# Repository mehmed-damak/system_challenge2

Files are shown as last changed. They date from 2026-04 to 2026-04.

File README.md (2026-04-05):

# SafeShift
SafeShift is a system meant to be retrofitted on new and/or old industrial vehicles. The Goal of Safeshift is to provide assistance in preventative maintenance and in safety (and limited power tracking to where it applies). SafeShift is meant to be modular and be a plug and play module, that can work on any vehicle both new and old.

## Physical Installation
The main SafeShift board is to be placed in space inside the drivers cabin. and the sensors respective connectors will be plugged into them. The sensors are to be bolted/fasted to their repective areas (defined below). _NOTE: not ALL sensors must be connected to use SafeShift_




## Connectivity and Dashboard
The Preventative Maintenance Part of the systam connects to a dashboard through wifi or bluetooth, and provides sensor reading, both past and present. A simple learning model from previous data shows the current status of the system based on the data gathered. 

## Safety 
SafeShift uses a combination of sensors to ensure real-time safety monitoring and intelligent decision-making in industrial vehicles. It integrates JSN-SR04T (ultrasonic sensor) for proximity and obstacle detection, RCWL-0516 (microwave radar sensor) for motion detection, ADXL345 (MEMS accelerometer) for vibration and tilt monitoring, DS18B20 (digital temperature sensor) for thermal monitoring, WCS1500 (Hall-effect current sensor) for system current measurement, and A3144 (Hall-effect sensor) for position and magnetic detection. These sensors enable features such as blind spot detection, pedestrian awareness, and environment-adaptive responses in dynamic industrial settings. Together, this multi-sensor approach provides reliable, low-cost, and scalable safety coverage, significantly improving operational safety and system awareness.

## Preventative Maintenance
SafeShift tracks the following parameters in Industrial Vehicles: Vibration in motor pumps, temperature of motor-pumps. it uses a simple DS18B20 to track temperature sensors and an ADXL345 for vibrations. There are 4 of each applicable to this system.

## Energy Tracking 
If the vehicle is equipped with an electrical system, consumption is monitored via real-time current data shown on the dashboard through the current sensor.
Note: The voltage is to be set by the user following the vehicles specifications.

## Usage
SafeShift is designed for simple and intuitive usage, requiring the operator to download and launch the mobile application and connect to the system via WiFi or Bluetooth.

run app

Once connected, the dashboard provides real-time monitoring of vehicle status and safety conditions.

If proximity is detected, a buzzer alarm is activated. 
If a pedestrian is detected, a buzzer alarm is also triggered. 
If the seatbelt is not fastened, an LED indicator is activated. 
If the door is not properly closed, an LED indicator is turned on. 
If the load is too heavy, a pressure LED is activated.

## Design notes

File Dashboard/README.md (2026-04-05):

# SafeShift — Vehicle Safety & Maintenance Dashboard

A student engineering competition project simulating a retrofit IoT safety
system for industrial excavators. Real-time sensor simulation with an embedded
XGBoost failure prediction model.

---

## Project structure

```
SafeShift/
├── server.py            # Python WebSocket simulation backend
├── dashboard.html       # Single-file frontend (open directly in browser)
├── retrain.py           # Model retraining script
├── xgboost_model.pkl    # Trained XGBoost failure prediction model
├── ai4i_fe.csv          # Training dataset (AI4I 2020 Predictive Maintenance)
├── requirements.txt     # Python dependencies
└── README.md
```

---

## Quick start

### 1. Create a virtual environment and install dependencies

```bash
python3 -m venv .venv
source .venv/bin/activate        # Windows: .venv\Scripts\activate
pip install -r requirements.txt
```

### 2. Start the server

```bash
python server.py
```

You should see:

```
====================================================
  SafeShift server running on ws://localhost:8765
  Open dashboard.html in your browser
  Press Ctrl+C to stop
====================================================
[AI] XGBoost failure model loaded successfully.
```

### 3. Open the dashboard

Open `dashboard.html` directly in your browser (no web server needed).

---

## Architecture

```
dashboard.html  ──WebSocket──▶  server.py
   (browser)    ◀──JSON 500ms──  (Python asyncio)
                                     │
                                     ├─ Sensor simulation classes
                                     ├─ ESP32Controller (safety logic)
                                     └─ FailurePredictor (XGBoost)
```

### Backend (`server.py`)

Simulates a full sensor suite and broadcasts a JSON state object to all
connected clients every 500 ms:

| Sensor class | Simulates |
|---|---|
| `HydraulicPressureSensor` | 0–400 bar with noise + spike suppression |
| `TemperatureSensor`  | Thermal lag model, scales with RPM |
| `VibrationSensor` | RPM-dependent + optional fault injection |
| `RuntimeCounter` | Service hours meter (accelerated for demo) |

The `ESP32Controller` class enforces safety interlocks:
- Relay opens if door is open, seatbelt is off, or pressure exceeds 280 bar
- Alerts are debounced (same alert cannot repeat within 3 seconds)
- Alert log capped at 50 entries, newest first

### Frontend (`dashboard.html`)

- Vanilla JS + CSS, no build step, no npm
- Chart.js (CDN) for the temperature sparkline only
- WebSocket auto-reconnects every 2 seconds if the server drops

---

## AI Failure Prediction

The XGBoost model predicts machine failure probability using only the three
inputs available from the dashboard:

| Dashboard data | Model feature |
|---|---|
| Air temperature (°C) | Air temperature (K) |
| Motor RPM | Rotational speed (rpm) |
| Service hours | Tool wear (min, scaled)  |

Two derived features are computed on the fly:
- `omega` = rpm × 2π / 60
- `pct_tool_life` = tool_wear / 220

**Model performance** (test set, 20% holdout, stratified):

| Metric | Value |
|---|---|
| ROC-AUC | 0.92  |
| PR-AUC | 0.33  |
| Recall (failure class) | 0.52 |

> PR-AUC is the most meaningful metric here given the 97/3 class imbalance.
> The model is weighted with `scale_pos_weight` to improve minority class recall.

### Retraining

To retrain the model from the raw dataset:

```bash
python retrain.py
```

This will clean the data (drops 27 inconsistent label rows), re-engineer
features, retrain with the same hyperparameters, print evaluation metrics,
and overwrite `xgboost_model.pkl`.

---

## Operator controls

| Control | Effect |
|---|---|
| Hydraulic pressure | Sets pressure set-point (0–400 bar) |
| Motor RPM | Sets motor speed (0–2500 rpm) |
| Air temperature | Overrides the thermal simulation (20–130 °C) |
| Service hours | Sets the runtime counter (0–500 h) |
| Door open toggle | Opens the cab door → triggers interlock |
| Seatbelt removed | Removes seatbelt → triggers interlock |
| Inject vibration fault | Adds a 2.5 g spike to the vibration sensor |
| Connect Bluetooth | UI indicator only (no real connection) |
| Internet | UI indicator only (no real connection) |

---

## Dependencies

| Package | Version  | Purpose |
|---|---|---|
| websockets | ≥ 16.0 | Async WebSocket server |
| xgboost | ≥ 3.2.0  | Failure prediction model |
| scikit-learn | ≥ 1.7.0  | Train/test split, metrics |
| numpy | ≥ 2.2.0  | Numerical computation |
| pandas | ≥ 2.3.0  | Feature DataFrame construction |

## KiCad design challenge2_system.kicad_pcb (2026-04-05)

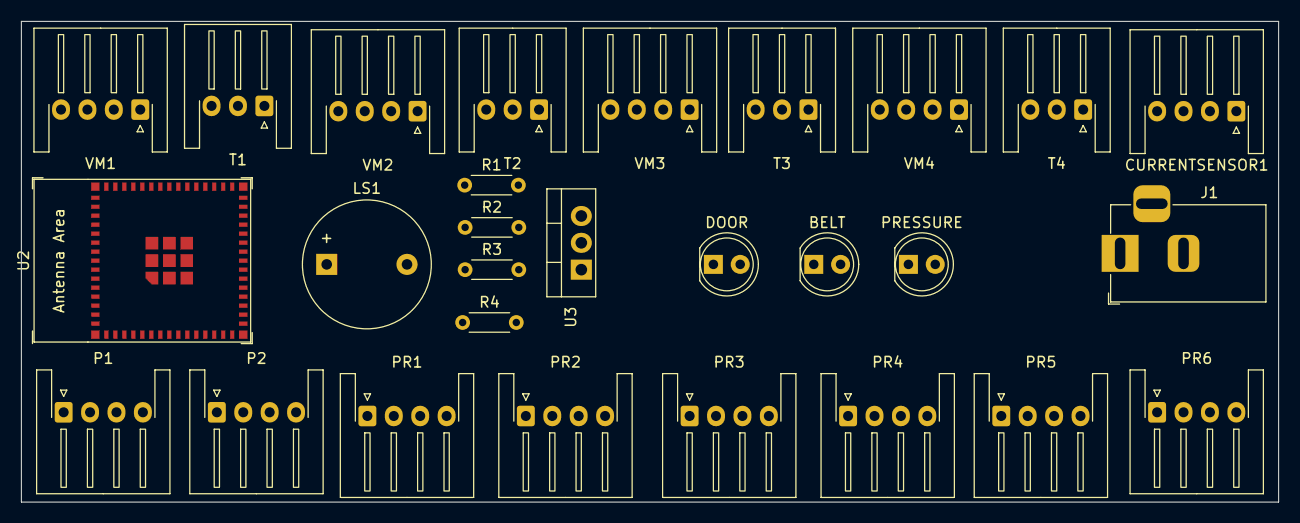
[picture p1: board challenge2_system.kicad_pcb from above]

Board: 2 copper layers, 119.0 x 45.5 mm, 28 parts (0 on the bottom side), 40 nets, no tracks yet.

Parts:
BELT: LED; LED_D5.0mm
CURRENTSENSOR1: Conn_01x04_Pin; JST_XH_S4B-XH-A-1_1x04_P2.50mm_Horizontal
DOOR: LED; LED_D5.0mm
J1: Barrel_Jack_Switch_Pin3Ring; BarrelJack_Horizontal
LS1: Speaker; Buzzer_12x9.5RM7.6
P1, P2: Conn_01x04_Pin; JST_XH_S4B-XH-A-1_1x04_P2.50mm_Horizontal
PR1, PR2, PR3, PR4, PR5, PR6: Conn_01x04_Pin; JST_XH_S4B-XH-A-1_1x04_P2.50mm_Horizontal
PRESSURE: LED; LED_D5.0mm
R1, R2, R3, R4: R; R_Axial_DIN0204_L3.6mm_D1.6mm_P5.08mm_Horizontal
T1, T2, T3, T4: Conn_01x03_Pin; JST_XH_S3B-XH-A-1_1x03_P2.50mm_Horizontal
U2: ESP32-S3-MINI-1
U3: LD1117V33; TO-220-3_Vertical
VM1, VM2, VM3, VM4: Conn_01x04_Pin; JST_XH_S4B-XH-A-1_1x04_P2.50mm_Horizontal

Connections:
+3V3: CURRENTSENSOR1.4, P1.1, P2.1, PR1.1, PR2.1, PR3.1, PR4.1, PR5.1, PR6.1, T1.1, T2.1, T3.1, T4.1, U3.2 (VO), VM1.3, VM2.3, VM3.3, VM4.3
/PIN A1: P1.3, U2.20 (GPIO16/U0CTS/ADC2_CH5/XTAL_32K_N)
/PINA2: P2.3, U2.24 (GPIO20/U1CTS/ADC2_CH9/CLK_OUT1/USB_D+)
/PINB1: P1.4, U2.19 (GPIO15/U0RTS/ADC2_CH4/XTAL_32K_P)
/PINB2: P2.4, U2.23 (GPIO19/U1RTS/ADC2_CH8/CLK_OUT2/USB_D-)
GND: BELT.1 (K), CURRENTSENSOR1.1, DOOR.1 (K), J1.3, LS1.1, P1.2, P2.2, PR1.4, PR2.4, PR3.4, PR4.4, PR5.4, PR6.4, PRESSURE.1 (K), T1.3, T2.3, T3.3, T4.3, U2.1 (GND), U2.2 (GND), U2.42 (GND), U2.43 (GND), U2.46 (GND), U2.47 (GND), U2.48 (GND), U2.49 (GND), U2.50 (GND), U2.51 (GND), U2.52 (GND), U2.53 (GND), U2.54 (GND), U2.55 (GND), U2.56 (GND), U2.57 (GND), U2.58 (GND), U2.59 (GND), U2.60 (GND), U2.61 (GND), U2.62 (GND), U2.63 (GND), U2.64 (GND), U2.65 (GND), U3.1 (GND), VM1.4, VM2.4, VM3.4, VM4.4
unnamed: CURRENTSENSOR1.3, U2.25 (GPIO21)
unnamed: DOOR.2 (A), R1.1
unnamed: BELT.2 (A), R2.1
unnamed: PRESSURE.2 (A), R4.1
unnamed: LS1.2, R3.2
unnamed: PR1.2, U2.35 (MTCK/GPIO39/CLK_OUT3/SUBSPICS1)
unnamed: PR1.3, U2.36 (MTDO/GPIO40/CLK_OUT2)
unnamed: PR2.2, U2.37 (MTDI/GPIO41/CLK_OUT1)
unnamed: PR2.3, U2.38 (MTMS/GPIO42)
unnamed: PR3.2, U2.26 (GPIO26)
unnamed: PR3.3, U2.28 (SPIIO4/GPIO33/FSPIHD/SUBSPIHD)
unnamed: PR4.2, U2.29 (SPIIO5/GPIO34/FSPICS0/SUBSPICS0)
unnamed: PR4.3, U2.31 (SPIIO6/GPIO35/FSPID/SUBSPID)
unnamed: PR5.2, U2.32 (SPIIO7/GPIO36/FSPICLK/SUBSPICLK)
unnamed: PR5.3, U2.33 (SPIDQS/GPIO37/FSPIQ/SUBSPIQ)
unnamed: PR6.2, U2.27 (GPIO47/SPICLK_P/SUBSPICLK_P_DIFF)
unnamed: PR6.3, U2.44 (GPIO46)
unnamed: T1.2, U2.10 (GPIO6/TOUCH6/ADC1_CH5)
unnamed: T2.2, U2.13 (GPIO9/TOUCH9/ADC1_CH8/FSPIHD/SUBSPIHD)
unnamed: T3.2, U2.21 (GPIO17/U1TXD/ADC2_CH6)
unnamed: T4.2, U2.16 (GPIO12/TOUCH12/ADC2_CH1/FSPICLK/FSPIIO6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)
unnamed: R3.1, U2.4 (GPIO0/BOOT)
unnamed: R2.2, U2.5 (GPIO1/TOUCH1/ADC1_CH0)
unnamed: R1.2, U2.6 (GPIO2/TOUCH2/ADC1_CH1)
unnamed: U2.8 (GPIO4/TOUCH4/ADC1_CH3), VM1.2
unnamed: U2.9 (GPIO5/TOUCH5/ADC1_CH4), VM1.1
unnamed: U2.11 (GPIO7/TOUCH7/ADC1_CH6), VM2.2
unnamed: U2.12 (GPIO8/TOUCH8/ADC1_CH7/SUBSPICS1), VM2.1
unnamed: U2.14 (GPIO10/TOUCH10/ADC1_CH9/FSPICS0/FSPIIO4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), VM4.2
unnamed: U2.15 (GPIO11/TOUCH11/ADC2_CH0/FSPID/FSPIIO5/S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), VM4.1
unnamed: U2.17 (GPIO13/TOUCH13/ADC2_CH2/FSPIQ/FSPIIO7/S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), VM3.2
unnamed: U2.18 (GPIO14/TOUCH14/ADC2_CH3/FSPIWP/FSPIDQS/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), VM3.1
unnamed: R4.2, U2.39 (U0TXD/GPIO43/CLK_OUT1)
unnamed: J1.1, U3.3 (VI)

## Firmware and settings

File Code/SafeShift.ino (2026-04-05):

/*
 * ============================================================
 *  SafeShift — Universal Industrial Vehicle Safety Kit
 *  Target: ESP32-S3-MINI-1
 *  Board:  ESP32S3 Dev Module (Arduino IDE)
 * ============================================================
 *
 *  SENSORS (from schematic):
 *    - 5× JSN-SR04T   Blind spot ultrasonic (PR1–PR5 connectors)
 *    - 2× RCWL-0516   Microwave motion (MWSENSOR_R1, MWSENSOR_F1)
 *    - 1× Microswitch  Door interlock (DOOR1)
 *    - 1× A3144        Hall effect seatbelt (T4 connector)
 *    - 1× DS18B20      Engine temperature (TS/VK3)
 *    - 1× ADXL345      Vibration (I2C)
 *    - 1× WCS1500      Current sensor (VM4 / CURRENTSENSOR1)
 *    - 1× Pressure transducer  Hydraulic (ADC pin)
 *
 *  OUTPUTS:
 *    - 1× Relay        Interlock (cuts ignition/lift)
 *    - 1× Buzzer       Audible alerts
 *    - 4× LEDs         Zone warning panel (G/Y/Y/R)
 *    - 1× Status LED   Board indicator (D3/R4)
 *
 *  CONNECTIVITY:
 *    - WiFi + MQTT     Dashboard telemetry
 *
 *  LIBRARIES REQUIRED (install via Arduino Library Manager):
 *    - PubSubClient       (MQTT)
 *    - OneWire            (DS18B20)
 *    - DallasTemperature  (DS18B20)
 *    - Adafruit ADXL345   (vibration)
 *    - Adafruit Unified Sensor
 *    - ArduinoJson        (payload serialisation)
 * ============================================================
 */

// ─── Core libraries ──────────────────────────────────────────
#include <Arduino.h>
#include <WiFi.h>
#include <PubSubClient.h>
#include <ArduinoJson.h>
#include <Wire.h>
#include <OneWire.h>
#include <DallasTemperature.h>
#include <Adafruit_Sensor.h>
#include <Adafruit_ADXL345_U.h>

// ─── WiFi / MQTT credentials ─────────────────────────────────
#define WIFI_SSID       "YOUR_WIFI_SSID"
#define WIFI_PASSWORD   "YOUR_WIFI_PASSWORD"
#define MQTT_BROKER     "192.168.1.100"   // your broker IP
#define MQTT_PORT       1883
#define MQTT_CLIENT_ID  "RetroGuard_01"
#define MQTT_TOPIC_STATE    "retroguard/state"
#define MQTT_TOPIC_ALERT    "retroguard/alert"
#define MQTT_TOPIC_CMD      "retroguard/cmd"   // incoming commands

// ─── PIN DEFINITIONS (ESP32-S3-MINI-1) ───────────────────────
// Mapped from schematic connectors + standard GPIO layout

// JSN-SR04T ultrasonic sensors (PR1–PR5)
// Each sensor: TRIG + ECHO pair
#define US_TRIG_1   1    // PR1 — rear left
#define US_ECHO_1   2
#define US_TRIG_2   3    // PR2 — rear centre
#define US_ECHO_2   4
#define US_TRIG_3   5    // PR3 — rear right
#define US_ECHO_3   6
#define US_TRIG_4   7    // PR4 — side left
#define US_ECHO_4   8
#define US_TRIG_5   9    // PR5 — side right
#define US_ECHO_5   10

// RCWL-0516 microwave radar (MWSENSOR_R1, MWSENSOR_F1)
#define MW_REAR     11   // MWSENSOR_R1 OUT pin
#define MW_FRONT    12   // MWSENSOR_F1 OUT pin

// Door microswitch (DOOR1)
#define DOOR_PIN    13   // active LOW when door closed

// A3144 Hall effect seatbelt (T4 connector)
#define BELT_PIN    14   // active LOW when buckled (open-collector)

// DS18B20 temperature (TS/VK3 — 1-Wire)
#define ONE_WIRE_BUS 15

// ADXL345 vibration (I2C — SDA/SCL)
#define SDA_PIN     17   // ESP32-S3 default I2C
#define SCL_PIN     18

// WCS1500 current sensor (VM4 / CURRENTSENSOR1 — analog)
#define CURRENT_PIN 16   // ADC1 channel

// Hydraulic pressure transducer (analog — 0.5–4.5V → divider → 3.3V)
#define PRESSURE_PIN 6   // ADC — GPIO6 / ADC1_CH5
// Note: after 10k/20k voltage divider: 4.5V → ~3.0V safe for ESP32-S3

// Outputs
#define RELAY_PIN   33   // HIGH = relay energised = circuit closed = OPERABLE
#define BUZZER_PIN  34   // active HIGH
#define LED_GREEN   35   // zone clear
#define LED_AMBER1  36   // advisory (3–5m)
#define LED_AMBER2  37   // warning  (1.5–3m)
#define LED_RED     38   // critical (<1.5m)
#define LED_STATUS  21   // onboard status LED (D3)

// ─── THRESHOLDS ───────────────────────────────────────────────
#define MAX_PRESSURE_BAR    280.0f  // hydraulic overload limit
#define MAX_TEMP_C          105.0f  // engine overtemp limit
#define MAX_VIBRATION_G     1.8f    // bearing fault threshold
#define WARN_VIBRATION_G    1.2f    // early vibration warning
#define SERVICE_INTERVAL_H  250.0f  // hours between services
#define SERVICE_WARN_H      20.0f   // warn when this many hours remain

// Blind spot zones (cm)
#define ZONE_CRITICAL_CM    150
#define ZONE_WARNING_CM     300
#define ZONE_ADVISORY_CM    500

// Hydraulic ADC conversion constants
// Sensor: 0–400 bar → 0.5–4.5V. After 10k/20k divider: 0.33–3.0V
// ESP32-S3 ADC: 12-bit = 0–4095 for 0–3.3V
#define PRESSURE_V_MIN      0.33f   // V at 0 bar (after divider)
#define PRESSURE_V_MAX      3.0f    // V at 400 bar (after divider)
#define PRESSURE_MAX_BAR    400.0f

// WCS1500: 0–200A → 1.0–4.5V analog output (datasheet: 11mV/A + offset)
// Sensitivity: ~0.011 V/A,  zero-current output ~2.5V (5V supply, so 1.25V at 3.3V pin)
#define WCS1500_ZERO_V      1.25f
#define WCS1500_SENS        0.0066f  // V/A after divider (11mV/A × 0.6)

// ─── TIMING ───────────────────────────────────────────────────
#define LOOP_INTERVAL_MS        100   // main sensor poll interval
#define MQTT_PUBLISH_INTERVAL   500   // state publish interval
#define TEMP_READ_INTERVAL      2000  // DS18B20 read interval (slow sensor)
#define MQTT_RECONNECT_INTERVAL 5000  // reconnect attempt interval
#define BUZZER_BEEP_MS          100   // short beep duration
#define US_SPIKE_IGNORE_MS      800   // ignore ultrasonic right after trigger

// Alert debounce — same alert type won't repeat within this window
#define ALERT_DEBOUNCE_MS       3000

// ─── OBJECT INSTANCES ─────────────────────────────────────────
WiFiClient        wifiClient;
PubSubClient      mqttClient(wifiClient);
OneWire           oneWire(ONE_WIRE_BUS);
DallasTemperature tempSensor(&oneWire);
Adafruit_ADXL345_Unified adxl = Adafruit_ADXL345_Unified(12345);

// ─── STATE VARIABLES ──────────────────────────────────────────

// Sensor readings (updated each loop)
float   s_pressureBar   = 0.0f;
float   s_tempC         = 25.0f;
float   s_vibrationG    = 0.0f;
float   s_currentA      = 0.0f;
bool    s_doorClosed    = true;
bool    s_beltBuckled   = true;
bool    s_mwRear        = false;
bool    s_mwFront       = false;
int     s_usDist[5]     = {500, 500, 500, 500, 500}; // cm per sensor

// Derived states
bool    d_relayOn       = true;   // true = operable
bool    d_overload      = false;
bool    d_overtemp      = false;
bool    d_highVibration = false;
bool    d_motionRear    = false;
bool    d_motionFront   = false;
String  d_worstZone     = "CLEAR"; // CLEAR / ADVISORY / WARNING / CRITICAL

// Runtime
unsigned long startMs           = 0;
float         runtimeHours      = 232.4f; // pre-seeded for demo realism
float         hoursToService    = 0.0f;

// Timing trackers
unsigned long lastLoopMs        = 0;
unsigned long lastPublishMs     = 0;
unsigned long lastTempReadMs    = 0;
unsigned long lastMqttAttemptMs = 0;
unsigned long buzzerOffMs       = 0;
bool          buzzerActive      = false;

// Alert debounce map: maps alert key → last fired timestamp
struct AlertRecord {
  String key;
  unsigned long lastFiredMs;
};
#define MAX_ALERTS 20
AlertRecord alertHistory[MAX_ALERTS];
int alertCount = 0;

// Alert log (last 50, for MQTT publish)
#define MAX_LOG 50
struct AlertEntry {
  String level;   // CRITICAL / WARNING / INFO
  String message;
  String detail;
  String timestamp;
};
AlertEntry alertLog[MAX_LOG];
int logHead = 0;

// ─── FORWARD DECLARATIONS ─────────────────────────────────────
void connectWiFi();
void connectMQTT();
void mqttCallback(char* topic, byte* payload, unsigned int length);
void readUltrasonics();
float readUltrasonicCm(int trigPin, int echoPin);
void readPressure();
void readTemperature();
void readVibration();
void readCurrent();
void readDigitalSensors();
void runFirmwareLogic();
String getUltrasoundZone(int distCm);
String getWorstZone();
void updateOutputs();
void publishState();
void publishAlert(String level, String message, String detail);
bool isDebounced(String key);
void addToLog(String level, String message, String detail);
String buildTimestamp();
String floatToStr(float val, int decimals);

// ─── SETUP ────────────────────────────────────────────────────
void setup() {
  Serial.begin(115200);
  delay(500);
  Serial.println("\n=============================");
  Serial.println("  RetroGuard v1.0 Booting...");
  Serial.println("=============================");

  // Output pins
  pinMode(RELAY_PIN,   OUTPUT); digitalWrite(RELAY_PIN,   HIGH); // default: operable
  pinMode(BUZZER_PIN,  OUTPUT); digitalWrite(BUZZER_PIN,  LOW);
  pinMode(LED_GREEN,   OUTPUT); digitalWrite(LED_GREEN,   LOW);
  pinMode(LED_AMBER1,  OUTPUT); digitalWrite(LED_AMBER1,  LOW);
  pinMode(LED_AMBER2,  OUTPUT); digitalWrite(LED_AMBER2,  LOW);
  pinMode(LED_RED,     OUTPUT); digitalWrite(LED_RED,     LOW);
  pinMode(LED_STATUS,  OUTPUT); digitalWrite(LED_STATUS,  HIGH); // on during boot

  // Ultrasonic TRIG pins
  pinMode(US_TRIG_1, OUTPUT); digitalWrite(US_TRIG_1, LOW);
  pinMode(US_TRIG_2, OUTPUT); digitalWrite(US_TRIG_2, LOW);
  pinMode(US_TRIG_3, OUTPUT); digitalWrite(US_TRIG_3, LOW);
  pinMode(US_TRIG_4, OUTPUT); digitalWrite(US_TRIG_4, LOW);
  pinMode(US_TRIG_5, OUTPUT); digitalWrite(US_TRIG_5, LOW);

  // Ultrasonic ECHO pins
  pinMode(US_ECHO_1, INPUT);
  pinMode(US_ECHO_2, INPUT);
  pinMode(US_ECHO_3, INPUT);
  pinMode(US_ECHO_4, INPUT);
  pinMode(US_ECHO_5, INPUT);

  // Microwave radar
  pinMode(MW_REAR,  INPUT);
  pinMode(MW_FRONT, INPUT);

  // Digital sensors
  pinMode(DOOR_PIN, INPUT_PULLUP);  // LOW = closed (reed/microswitch)
  pinMode(BELT_PIN, INPUT_PULLUP);  // LOW = buckled (A3144 open-collector)

  // I2C for ADXL345
  Wire.begin(SDA_PIN, SCL_PIN);

  // DS18B20
  tempSensor.begin();
  Serial.printf("DS18B20 devices found: %d\n", tempSensor.getDeviceCount());

  // ADXL345
  if (!adxl.begin()) {
    Serial.println("[WARN] ADXL345 not found — check wiring");
  } else {
    adxl.setRange(ADXL345_RANGE_4_G);
    Serial.println("[OK] ADXL345 ready");
  }

  // ADC attenuation for pressure + current pins
  // ESP32-S3: use analogSetPinAttenuation for 0–3.3V range
  analogSetPinAttenuation(PRESSURE_PIN, ADC_11db);
  analogSetPinAttenuation(CURRENT_PIN,  ADC_11db);

  startMs = millis();

  // WiFi + MQTT
  connectWiFi();
  mqttClient.setServer(MQTT_BROKER, MQTT_PORT);
  mqttClient.setCallback(mqttCallback);
  mqttClient.setBufferSize(2048);
  connectMQTT();

  digitalWrite(LED_STATUS, LOW); // boot complete

  // Startup grace period — give sensors time to settle
  delay(1000);

  addToLog("INFO", "System online", "RetroGuard v1.0 ready");
  Serial.println("[OK] Boot complete. Entering main loop.");
}

// ─── MAIN LOOP ────────────────────────────────────────────────
void loop() {
  unsigned long now = millis();

  // MQTT keep-alive
  if (!mqttClient.connected()) {
    if (now - lastMqttAttemptMs > MQTT_RECONNECT_INTERVAL) {
      lastMqttAttemptMs = now;
      connectMQTT();
    }
  }
  mqttClient.loop();

  // Buzzer auto-off
  if (buzzerActive && now > buzzerOffMs) {
    digitalWrite(BUZZER_PIN, LOW);
    buzzerActive = false;
  }

  // Main sensor poll at LOOP_INTERVAL_MS
  if (now - lastLoopMs < LOOP_INTERVAL_MS) return;
  lastLoopMs = now;

  // Update runtime
  runtimeHours = 232.4f + (float)(now - startMs) / 3600000.0f;
  hoursToService = SERVICE_INTERVAL_H - runtimeHours;

  // ── Read all sensors ──
  readDigitalSensors();  // door, belt, microwave
  readUltrasonics();     // 5× JSN-SR04T
  readPressure();        // hydraulic transducer
  readCurrent();         // WCS1500

  // Temperature is slow (DS18B20 needs ~750ms conversion)
  if (now - lastTempReadMs > TEMP_READ_INTERVAL) {
    readTemperature();
    lastTempReadMs = now;
  }

  readVibration();       // ADXL345

  // ── Run safety/maintenance logic ──
  runFirmwareLogic();

  // ── Drive outputs ──
  updateOutputs();

  // ── MQTT publish ──
  if (now - lastPublishMs > MQTT_PUBLISH_INTERVAL) {
    publishState();
    lastPublishMs = now;
  }
}

// ─── SENSOR READERS ───────────────────────────────────────────

void readDigitalSensors() {
  // Door: microswitch — LOW when door closed (INPUT_PULLUP)
  s_doorClosed  = (digitalRead(DOOR_PIN) == LOW);

  // Belt: A3144 hall effect — LOW when magnet present = buckled (open-collector + pullup)
  s_beltBuckled = (digitalRead(BELT_PIN) == LOW);

  // RCWL-0516: HIGH when motion detected
  s_mwRear  = (digitalRead(MW_REAR)  == HIGH);
  s_mwFront = (digitalRead(MW_FRONT) == HIGH);
}

void readUltrasonics() {
  // Poll each sensor with 30ms stagger to avoid cross-triggering
  int trigPins[] = {US_TRIG_1, US_TRIG_2, US_TRIG_3, US_TRIG_4, US_TRIG_5};
  int echoPins[] = {US_ECHO_1, US_ECHO_2, US_ECHO_3, US_ECHO_4, US_ECHO_5};

  for (int i = 0; i < 5; i++) {
    float d = readUltrasonicCm(trigPins[i], echoPins[i]);
    if (d > 0 && d <= 500) {
      s_usDist[i] = (int)d;
    } else {
      s_usDist[i] = 500; // no echo = clear
    }
    delay(30); // stagger — prevents echo cross-talk between sensors
  }
}

float readUltrasonicCm(int trigPin, int echoPin) {
  // JSN-SR04T requires 20µs trigger (vs HC-SR04's 10µs)
  digitalWrite(trigPin, LOW);
  delayMicroseconds(4);
  digitalWrite(trigPin, HIGH);
  delayMicroseconds(20);  // JSN-SR04T spec
  digitalWrite(trigPin, LOW);

  // Timeout 25ms = ~4.25m max range
  long duration = pulseIn(echoPin, HIGH, 25000);
  if (duration == 0) return 0; // timeout = nothing detected

  return (float)duration / 58.0f; // convert µs to cm
}

void readPressure() {
  // Read raw ADC (12-bit, 0–4095)
  int raw = analogRead(PRESSURE_PIN);
  float voltage = (raw / 4095.0f) * 3.3f;

  // Convert back through divider to get transducer voltage
  // Divider: 10k + 20k → Vout = Vin × (20/30) → Vin = Vout × (30/20)
  float vTransducer = voltage * 1.5f;

  // Map 0.5–4.5V → 0–400 bar
  float bar = (vTransducer - 0.5f) / 4.0f * PRESSURE_MAX_BAR;
  s_pressureBar = max(0.0f, bar);

  // ESP32-S3 ADC nonlinearity correction (simplified Espressif lookup)
  // For production: use esp_adc_cal_characterize()
  // For prototype: clamp to physically plausible range
  s_pressureBar = constrain(s_pressureBar, 0.0f, PRESSURE_MAX_BAR);
}

void readTemperature() {
  // Request conversion (non-blocking would be better for production)
  tempSensor.requestTemperatures();
  float t = tempSensor.getTempCByIndex(0);
  if (t != DEVICE_DISCONNECTED_C && t > -50.0f && t < 200.0f) {
    s_tempC = t;
  }
}

void readVibration() {
  sensors_event_t event;
  adxl.getEvent(&event);

  // Magnitude of acceleration vector (g)
  float ax = event.acceleration.x / 9.81f;
  float ay = event.acceleration.y / 9.81f;
  float az = event.acceleration.z / 9.81f;

  // Subtract 1g gravity from Z (static component when mounted flat)
  az = az - 1.0f;

  // RMS magnitude
  s_vibrationG = sqrt(ax*ax + ay*ay + az*az);

  // Clamp to sane range
  s_vibrationG = constrain(s_vibrationG, 0.0f, 10.0f);
}

void readCurrent() {
  // WCS1500: analog 0–200A
  // Output: ~2.5V at 0A (on 5V supply). After divider to ESP32-S3: ~1.25V at 0A
  // Sensitivity: 11mV/A on 5V → ~6.6mV/A after divider
  int raw = analogRead(CURRENT_PIN);
  float voltage = (raw / 4095.0f) * 3.3f;
  float current = (voltage - WCS1500_ZERO_V) / WCS1500_SENS;
  s_currentA = max(0.0f, current);
  s_currentA = constrain(s_currentA, 0.0f, 200.0f);
}

// ─── FIRMWARE LOGIC ───────────────────────────────────────────

void runFirmwareLogic() {
  unsigned long now = millis();
  bool relayOk = true;

  // ── Safety checks ──

  // 1. Hydraulic overload (weight lock)
  if (s_pressureBar > MAX_PRESSURE_BAR) {
    d_overload = true;
    relayOk = false;
    if (!isDebounced("overload")) {
      publishAlert("CRITICAL", "Overload detected",
                   floatToStr(s_pressureBar, 0) + " bar (max " +
                   floatToStr(MAX_PRESSURE_BAR, 0) + " bar)");
      addToLog("CRITICAL", "Overload",
               floatToStr(s_pressureBar, 0) + " bar");
    }
  } else {
    d_overload = false;
  }

  // 2. Door interlock
  if (!s_doorClosed) {
    relayOk = false;
    if (!isDebounced("door_open")) {
      publishAlert("CRITICAL", "Door open", "Interlock active");
      addToLog("CRITICAL", "Door open", "Interlock active");
    }
  }

  // 3. Seatbelt interlock
  if (!s_beltBuckled) {
    relayOk = false;
    if (!isDebounced("belt_unbuckled")) {
      publishAlert("CRITICAL", "Seatbelt unbuckled", "Interlock active");
      addToLog("CRITICAL", "Seatbelt unbuckled", "Interlock active");
    }
  }

  // 4. Pedestrian detection (RCWL-0516)
  //    Motion confirmed from rear sensor = elevated danger
  d_motionRear  = s_mwRear;
  d_motionFront = s_mwFront;

  if (s_mwRear && !isDebounced("mw_rear")) {
    publishAlert("WARNING", "Motion detected — rear", "RCWL-0516 triggered");
    addToLog("WARNING", "Rear motion", "RCWL-0516");
  }
  if (s_mwFront && !isDebounced("mw_front")) {
    publishAlert("WARNING", "Motion detected — front", "RCWL-0516 triggered");
    addToLog("WARNING", "Front motion", "RCWL-0516");
  }

  // 5. Blind spot zones
  d_worstZone = getWorstZone();

  if (d_worstZone == "CRITICAL" && !isDebounced("blindspot_crit")) {
    publishAlert("CRITICAL", "Blind spot critical",
                 "Object <150cm detected");
    addToLog("CRITICAL", "Blind spot", "<150cm");
  } else if (d_worstZone == "WARNING" && !isDebounced("blindspot_warn")) {
    publishAlert("WARNING", "Blind spot warning",
                 "Object 150–300cm");
    addToLog("WARNING", "Blind spot", "150–300cm");
  }

  // ── Maintenance checks ──

  // 6. Engine overtemp
  d_overtemp = (s_tempC > MAX_TEMP_C);
  if (d_overtemp && !isDebounced("overtemp")) {
    publishAlert("WARNING", "Engine overtemp",
                 floatToStr(s_tempC, 1) + "°C (max " +
                 floatToStr(MAX_TEMP_C, 0) + "°C)");
    addToLog("WARNING", "Overtemp",
             floatToStr(s_tempC, 1) + "°C");
  }

  // 7. High vibration (bearing wear indicator)
  d_highVibration = (s_vibrationG > MAX_VIBRATION_G);
  bool warnVibration = (s_vibrationG > WARN_VIBRATION_G && !d_highVibration);

  if (d_highVibration && !isDebounced("vibration_crit")) {
    publishAlert("CRITICAL", "High vibration",
                 floatToStr(s_vibrationG, 2) + " g — check bearings");
    addToLog("CRITICAL", "High vibration",
             floatToStr(s_vibrationG, 2) + " g");
  } else if (warnVibration && !isDebounced("vibration_warn")) {
    publishAlert("WARNING", "Vibration elevated",
                 floatToStr(s_vibrationG, 2) + " g");
    addToLog("WARNING", "Vibration", floatToStr(s_vibrationG, 2) + " g");
  }

  // 8. Service due
  if (hoursToService < SERVICE_WARN_H && hoursToService > 0 &&
      !isDebounced("service_due")) {
    publishAlert("INFO", "Service due soon",
                 floatToStr(hoursToService, 1) + " hrs remaining");
    addToLog("INFO", "Service due",
             floatToStr(hoursToService, 1) + " hrs");
  }
  if (hoursToService <= 0 && !isDebounced("service_overdue")) {
    publishAlert("WARNING", "Service overdue",
                 "Past interval by " +
                 floatToStr(-hoursToService, 1) + " hrs");
    addToLog("WARNING", "Service overdue",
             floatToStr(-hoursToService, 1) + " hrs late");
  }

  // ── Commit relay state ──
  d_relayOn = relayOk;
}

String getUltrasoundZone(int distCm) {
  if (distCm <= 0 || distCm >= 500)  return "CLEAR";
  if (distCm < ZONE_CRITICAL_CM)     return "CRITICAL";
  if (distCm < ZONE_WARNING_CM)      return "WARNING";
  if (distCm < ZONE_ADVISORY_CM)     return "ADVISORY";
  return "CLEAR";
}

String getWorstZone() {
  int worstPriority = 0;
  String worst = "CLEAR";
  const char* zones[] = {"CLEAR", "ADVISORY", "WARNING", "CRITICAL"};

  for (int i = 0; i < 5; i++) {
    String z = getUltrasoundZone(s_usDist[i]);
    int pri = 0;
    if (z == "ADVISORY") pri = 1;
    else if (z == "WARNING")  pri = 2;
    else if (z == "CRITICAL") pri = 3;

    if (pri > worstPriority) {
      worstPriority = pri;
      worst = z;
    }
  }
  return worst;
}

// ─── OUTPUTS ──────────────────────────────────────────────────

void updateOutputs() {
  // ── Relay ──
  digitalWrite(RELAY_PIN, d_relayOn ? HIGH : LOW);

  // ── LED warning panel ──
  // Shows worst blind spot zone
  bool isClear    = (d_worstZone == "CLEAR");
  bool isAdvisory = (d_worstZone == "ADVISORY");
  bool isWarning  = (d_worstZone == "WARNING");
  bool isCritical = (d_worstZone == "CRITICAL");

  // Override all LEDs to RED if relay interlocked
  if (!d_relayOn) {
    digitalWrite(LED_GREEN,  LOW);
    digitalWrite(LED_AMBER1, LOW);
    digitalWrite(LED_AMBER2, LOW);
    digitalWrite(LED_RED,    HIGH);
  } else {
    digitalWrite(LED_GREEN,  isClear    ? HIGH : LOW);
    digitalWrite(LED_AMBER1, isAdvisory ? HIGH : LOW);
    digitalWrite(LED_AMBER2, isWarning  ? HIGH : LOW);
    digitalWrite(LED_RED,    isCritical ? HIGH : LOW);
  }

  // ── Status LED ── heartbeat every 1s
  digitalWrite(LED_STATUS, (millis() / 1000) % 2 == 0 ? HIGH : LOW);

  // ── Buzzer ──
  if (!buzzerActive) {
    if (!d_relayOn || isCritical || d_highVibration) {
      // Continuous buzzer for critical states
      digitalWrite(BUZZER_PIN, HIGH);
      buzzerActive = true;
      buzzerOffMs  = millis() + 500; // 500ms on
    } else if (isWarning || s_mwRear || s_mwFront) {
      // Short beep for warnings
      digitalWrite(BUZZER_PIN, HIGH);
      buzzerActive = true;
      buzzerOffMs  = millis() + BUZZER_BEEP_MS;
    }
  }
}

// ─── MQTT ─────────────────────────────────────────────────────
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
